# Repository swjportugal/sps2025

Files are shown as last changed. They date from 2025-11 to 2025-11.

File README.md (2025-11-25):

# SPS 2025 Nuremberg

SWJ will be showcasing its development capabilities in embedded Software and Hardware development, Validation & Testing and PMTs. Visit us in Hall 6, Stand 430.

This repository contains contact information and technical information for all demos showcased at SPS.

# SWJ at SPS: Daniel Mraß

<table border=0 >
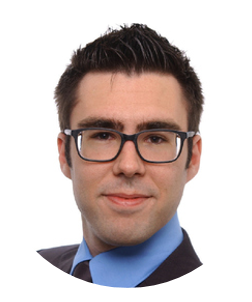
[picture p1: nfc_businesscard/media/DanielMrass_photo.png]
<tr><td></td>
<td>Angestellt, Projektingenieur<br/>
&nbsp; <br/>
SWJ Germany GmbH<br/>
Email: <a href="mailto:Daniel.Mrass@swj.de">Daniel.Mrass@swj.de</a><br/>
Web: <a href="www.swj.de">https://www.swj.de</a>
 </td></tr></table>

## NFC Business card

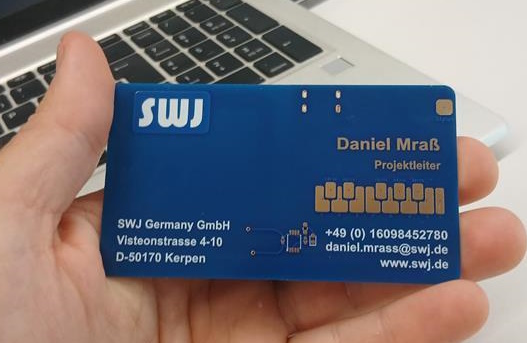
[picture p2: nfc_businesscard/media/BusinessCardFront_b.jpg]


The business card showcases an 0.8mm PCB in the traditional 85x55mm format.

We designed the PCB tracks in a **shape that creates an NFC antenna** and added an IC from NXP to provide quick transfer of contact information. A LED was also added,  so the user would get the unusual feedback of failed and successful attempts at NFC communication (short led pulse = failed; long led = succeeded)

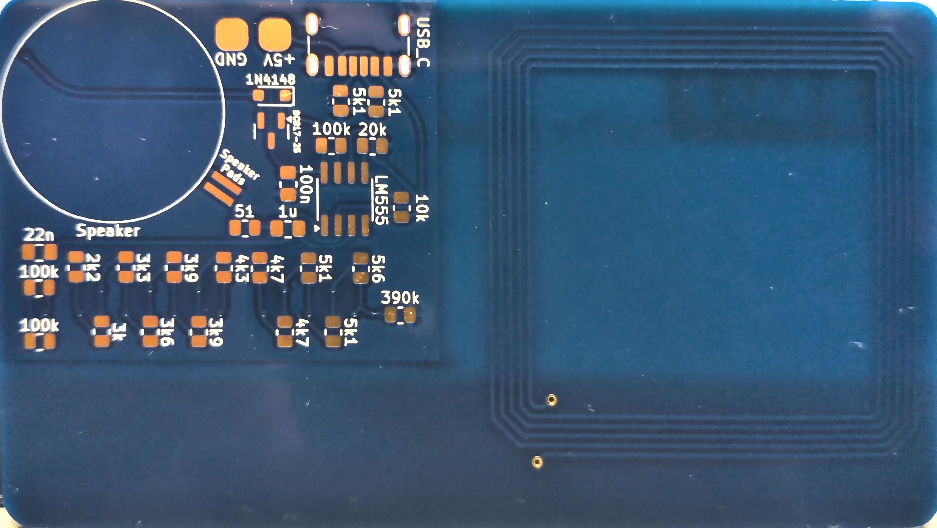
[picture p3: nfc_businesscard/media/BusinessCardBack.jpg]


Further, the team decided to add a "cool" factor to the business card by creating a **sound synthesizer** from the classic **555 timer**. What better way to flex your E/E knowledge? 

You can find the [BOM and schematics to populate this circuit and build your own synthesizer here](nfc_businesscard/ee_schematic/SWJ_NFC_BusinessCard.pdf).

## Smart controlled Windmills

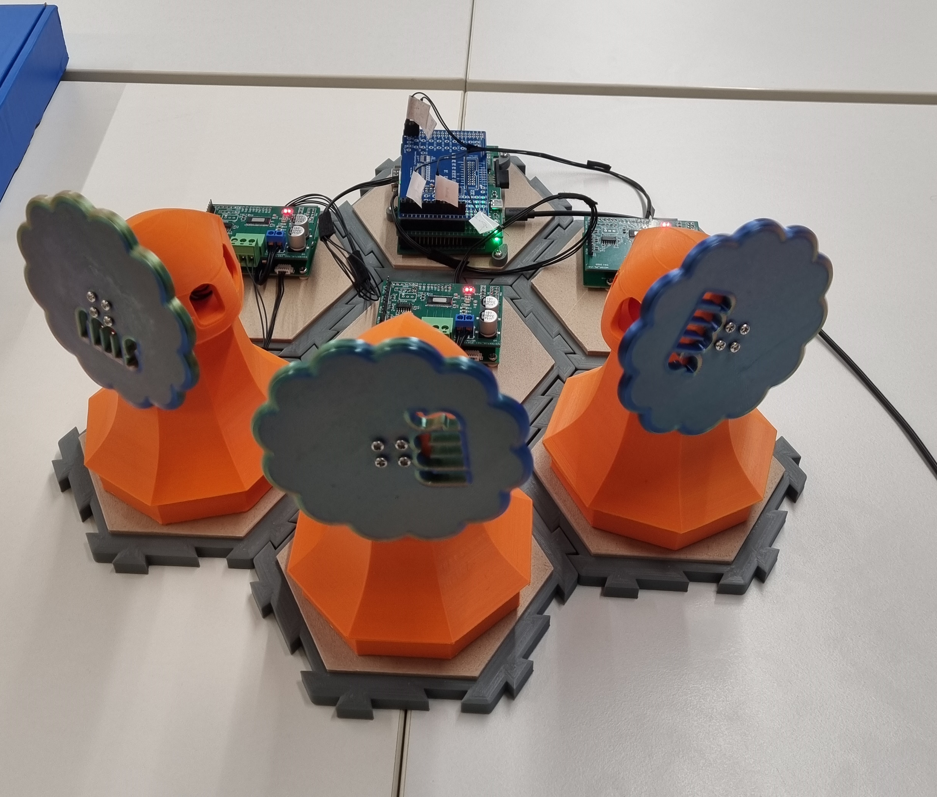
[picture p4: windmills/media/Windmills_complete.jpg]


The windmill demo showcases a distributed control system with a cascaded closed loop approach.

The solution is entirely designed by SWJ: mechanics, electronics and software.

A [detailed presentation can be found here](windmills/251110_WindmillDemo_Overview(Coisa).pdf) (incl. system diagrams and component identifications)

### System Architecture

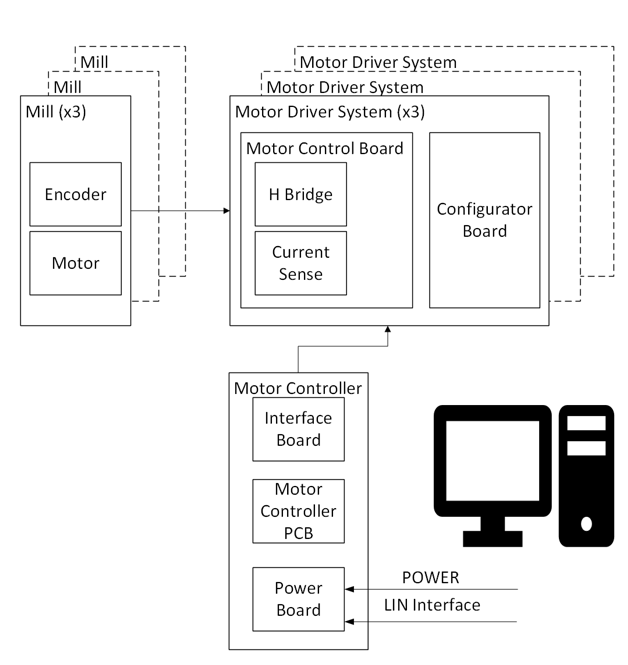
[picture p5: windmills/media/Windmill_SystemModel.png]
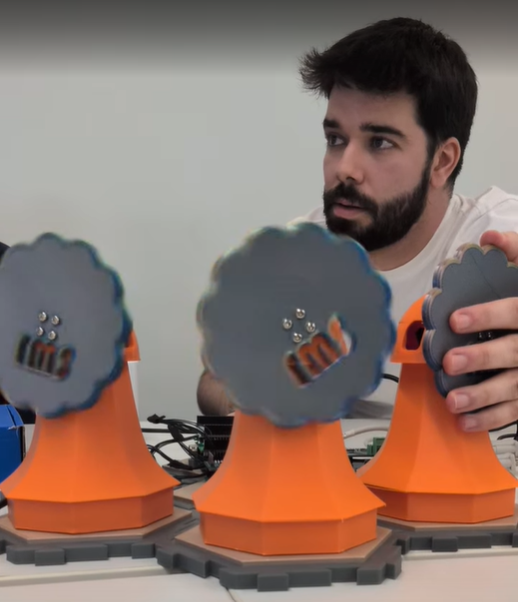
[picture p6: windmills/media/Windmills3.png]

   
At the **lower** level the windmills have a motor with an encoder on the output shaft (before the reduction box) to allow precise control of speed and continuously sense the real rotation and stall and error conditions.

At the **high level**, a control loop was created in Vector CANoe that continuously queries the motors status (current, speed, errors) and updates the target speed.
This creates dynamic behaviours that produce different, selectable, modes:

* Constant sum of speed: if any windmill is blocked or has its speed reduced, the other windmills spun up so that the sum of all speeds remains constant within the system
* Follow the leader: by manipulating one windmill, the others will follow (i.e. if you slow it down, the others slow down; if you block it, the others block too)
* Winding clock: if you spin up the windmill manually, the others spin up as well, and their speed slowly decays as if winding down a spring

#### This project is a combination of multiple disciplines:
* Electronics design: for the Windmill motor drivers and the master STM low level controller (speed)

Check the Schematics here: [ee_schematics](windmills/ee_schematics)

* Software (Embedded and Control): embedded software for the STM low level controller (speed), and CANoe high level control

Check the Software here: [sw_canoe_simulation](windmills/sw_canoe_simulation)

* Mechanical design: 3D models for the windmills, base and overall mounting points  

Find 3D models here: [3dmodels_mechanical](windmills/3dmodels_mechanical)

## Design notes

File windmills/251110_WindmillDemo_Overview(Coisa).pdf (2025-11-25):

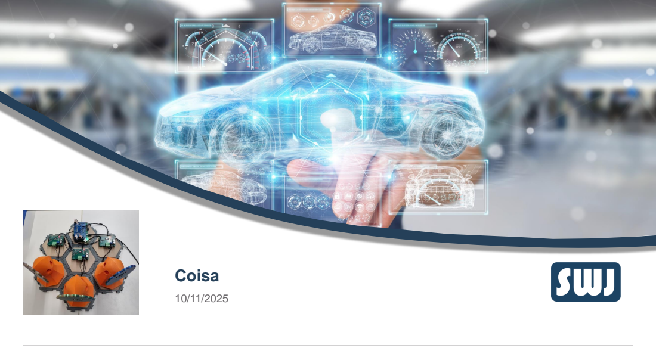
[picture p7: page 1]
Coisa

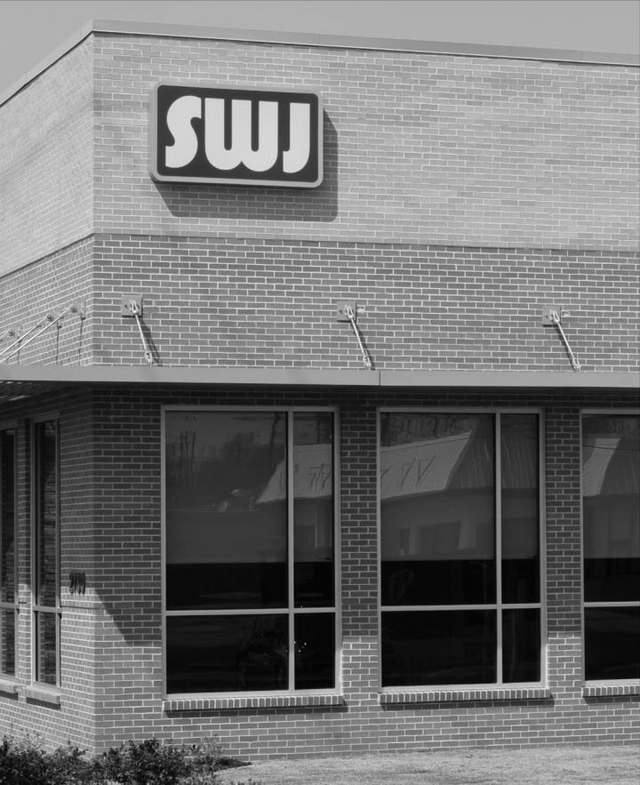
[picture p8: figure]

1

2

3

# Agenda

Copyright © 2022 SWJ. Alle Rechte vorbehalten. Vertraulich. | 2 | 25. November 2025

# Goals and Timeline

# PC control software

# Physical system

# Lessons learned

# Goals

- Coisa shall present some type of physical movement;
- A user shall be able to interact with Coisa;
- Coisa shall atract the atention;
- Coisa shall present SWJ capabilities.
3 | 25/11/2025

# Timeline

4 | 25/11/2025

# 20 Oct Hardware

# 10 Nov Software

# 25 Nov Fair Display

# Overall system

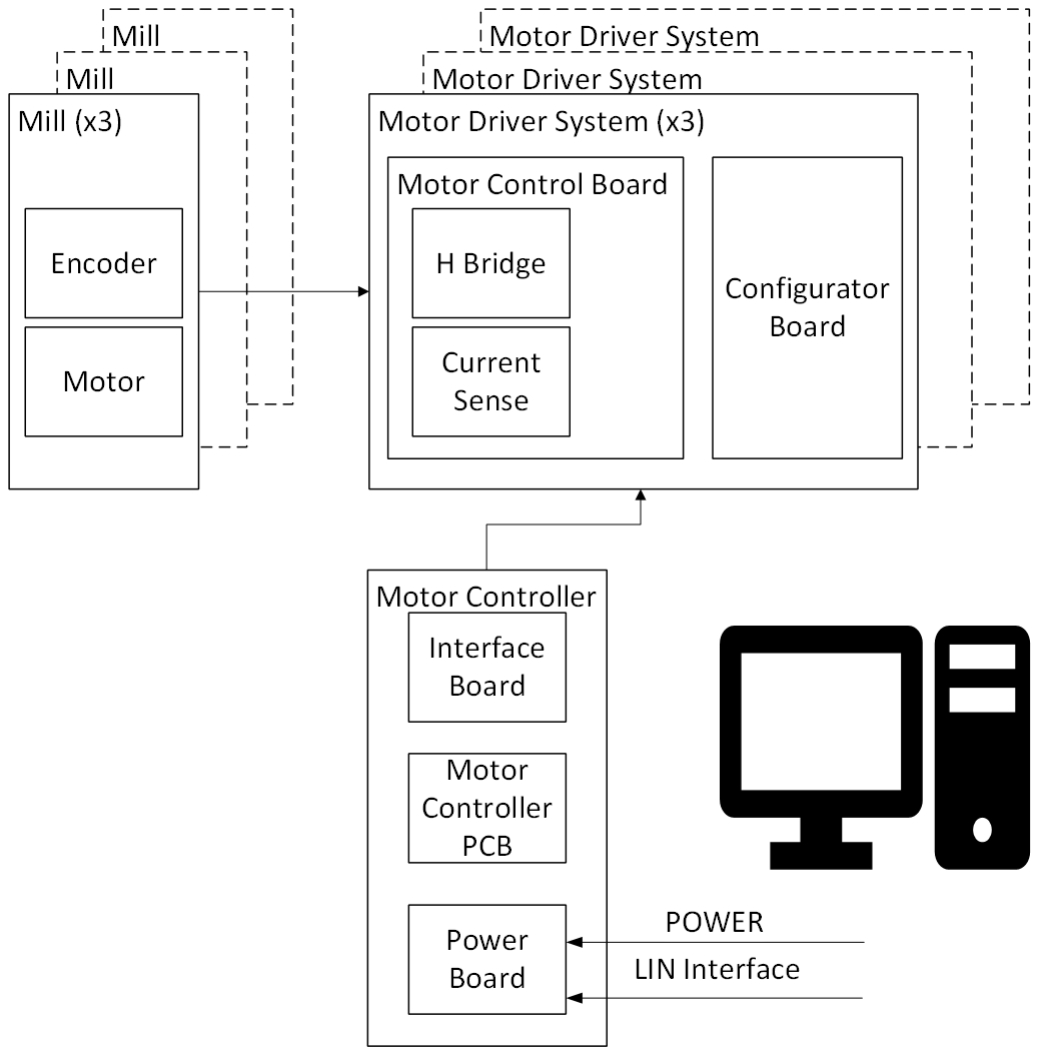
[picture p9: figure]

Copyright © 2022 SWJ. Alle Rechte vorbehalten. Vertraulich. | 5 | 25. November 2025

# - The visitor is invited to touch the mills to test the

system response;

- PC controls the high level behavior, mills interaction;

# - The motor controller controls each mill individualy to a

setpoint of speed.

# PC Software

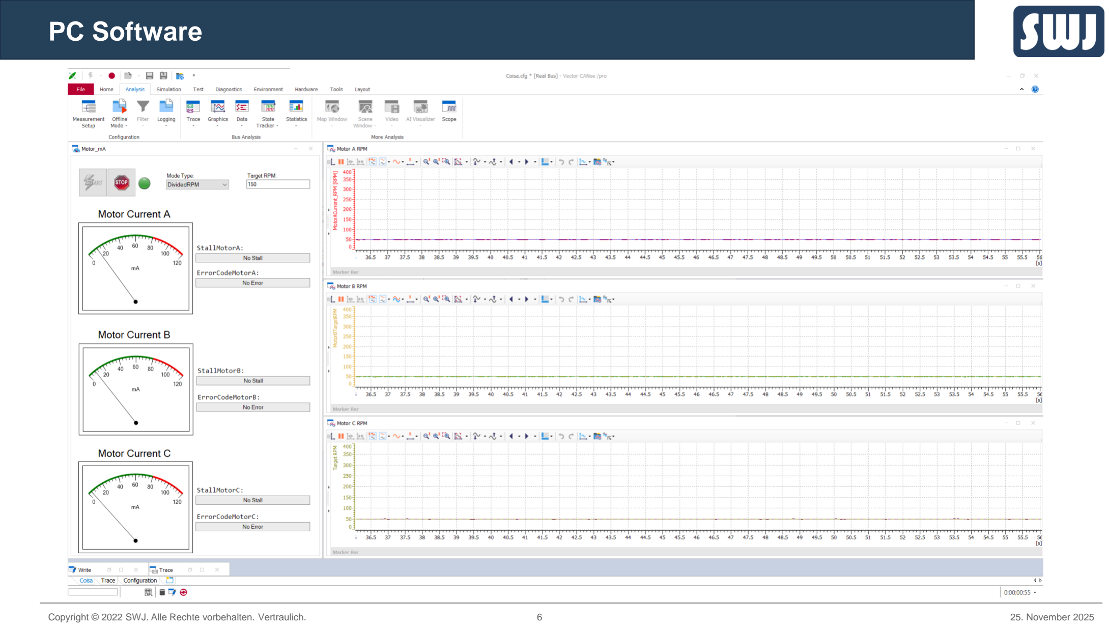
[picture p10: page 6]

Copyright © 2022 SWJ. Alle Rechte vorbehalten. Vertraulich. | 6 | 25. November 2025

# Physical System

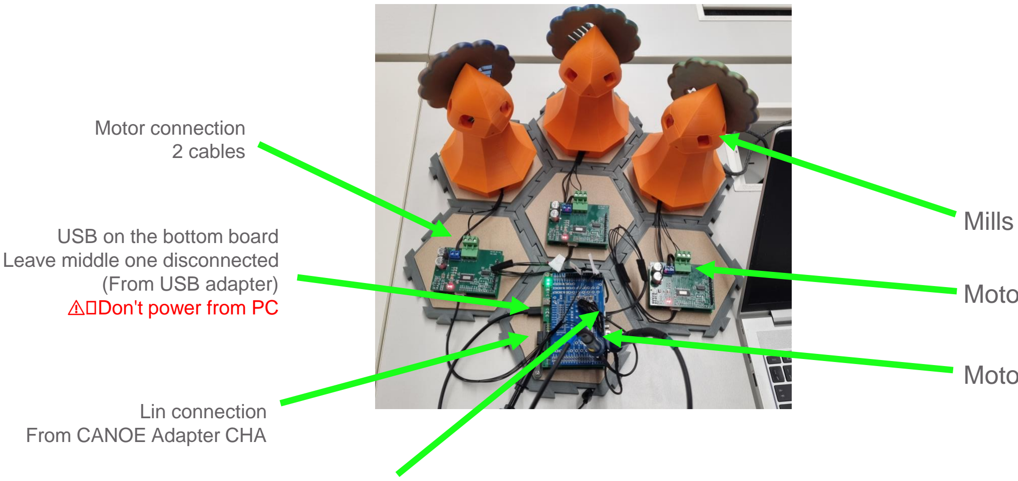
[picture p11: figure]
Mills USB on the bottom board; Leave middle one disconnected (From USB adapter) ⚠️Don't power from PC; Lin connection From CANOE Adapter CHA; Motor connection 2 cables

Copyright © 2022 SWJ. Alle Rechte vorbehalten. Vertraulich. | 7 | 25. November 2025

# Motor Driver

# Motor Controller

# Motors A to C labeled

# Embedded Software Architecture

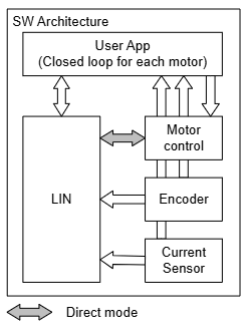
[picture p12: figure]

Copyright © 2022 SWJ. Alle Rechte vorbehalten. Vertraulich. | 8 | 25. November 2025

# Timming and controller

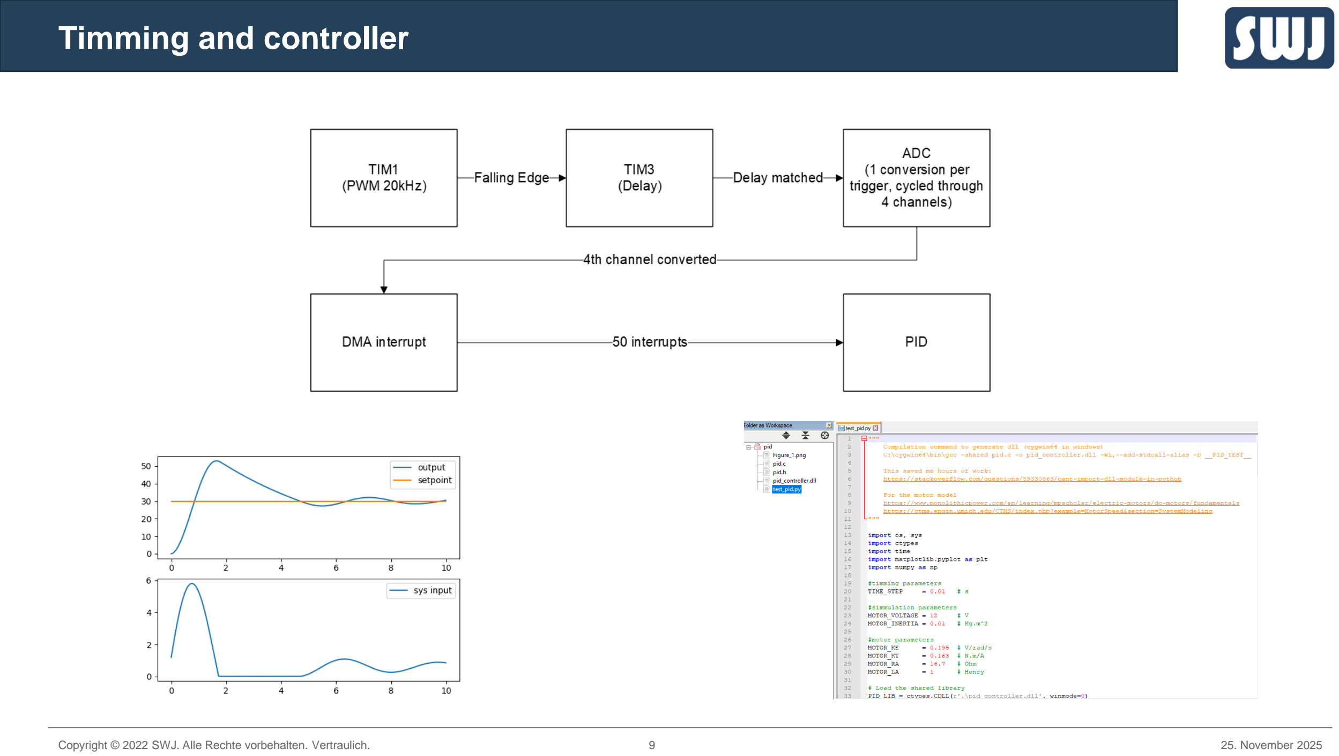
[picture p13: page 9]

Copyright © 2022 SWJ. Alle Rechte vorbehalten. Vertraulich. | 9 | 25. November 2025

# State machine

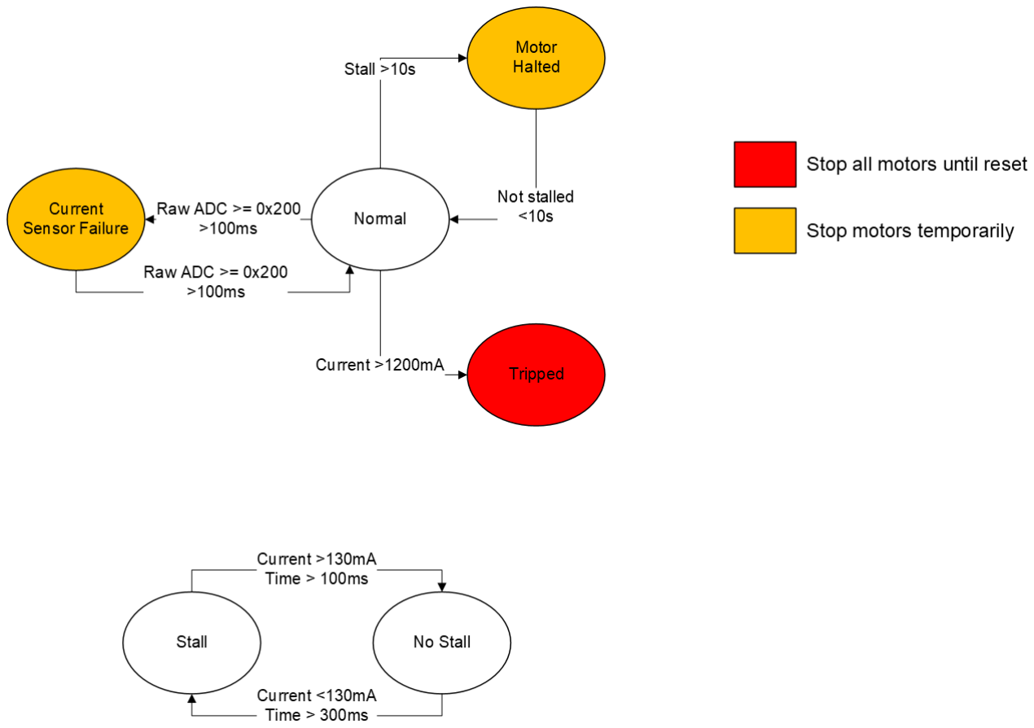
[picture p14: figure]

Copyright © 2022 SWJ. Alle Rechte vorbehalten. Vertraulich. | 10 | 25. November 2025

# Lessons Learned

Copyright © 2022 SWJ. Alle Rechte vorbehalten. Vertraulich. | 11 | 25. November 2025

# - Hardware

- Usage of protection mechanisms.

# DANKE

## taiku

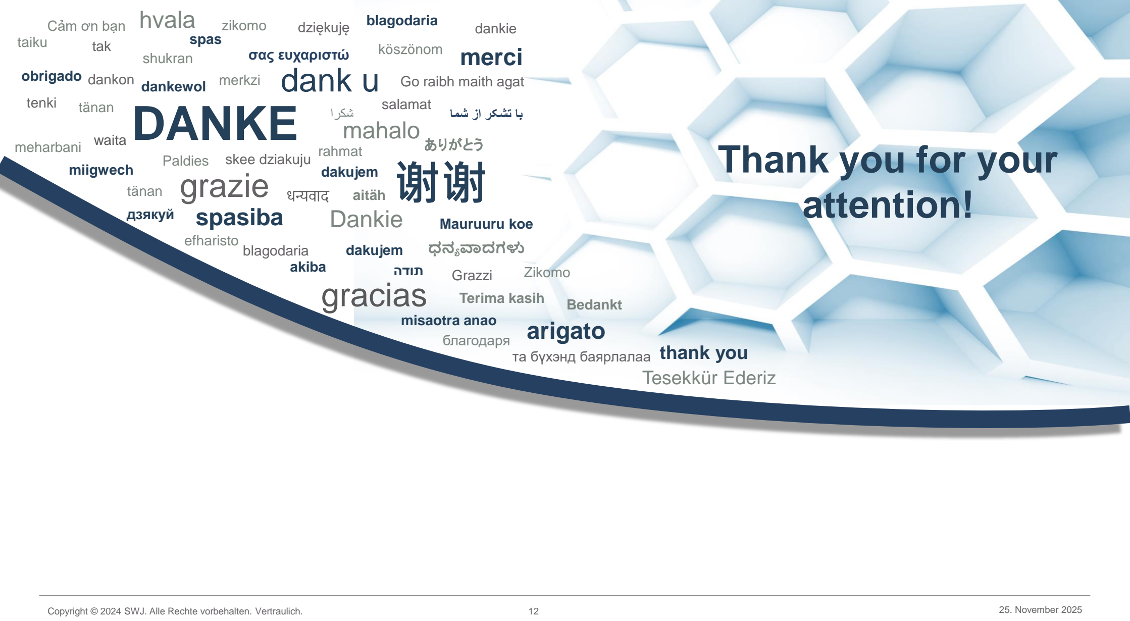
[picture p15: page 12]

# thank you

## tänan

## meharbani

# hvala

# Dankie

## ありがとう

## شكرا

## благодаря

## tak

# grazie

## dankon

## aitäh

## salamat

# gracias

# arigato

## dakujem

## shukran obrigado

miigwech | dakujem

## tenki

## waita

## spas

## merkzi

## efharisto blagodaria

## dankie

# spasiba

## Paldies

# Tesekkür Ederiz

## Bedankt

tänan | 谢谢

## σας ευχαριστώ

## תודה

# mahalo

## धन्यवाद

## Terima kasih

## Go raibh maith agat

## ಧನ್ಯ ವಾದಗಳು

## misaotra anao

## Grazzi

## Mauruuru koe

# dank u

## та бүхэнд баярлалаа

## Zikomo

## با تشکر از شما

Cảm ơn bạn | dziękuję

## дзякуй

## rahmat

## köszönom

## blagodaria

## skee dziakuju

## akiba

## zikomo

## dankewol

# merci

# Thank you for your attention!

Copyright © 2024 SWJ. Alle Rechte vorbehalten. Vertraulich. | 12 | 25. November 2025

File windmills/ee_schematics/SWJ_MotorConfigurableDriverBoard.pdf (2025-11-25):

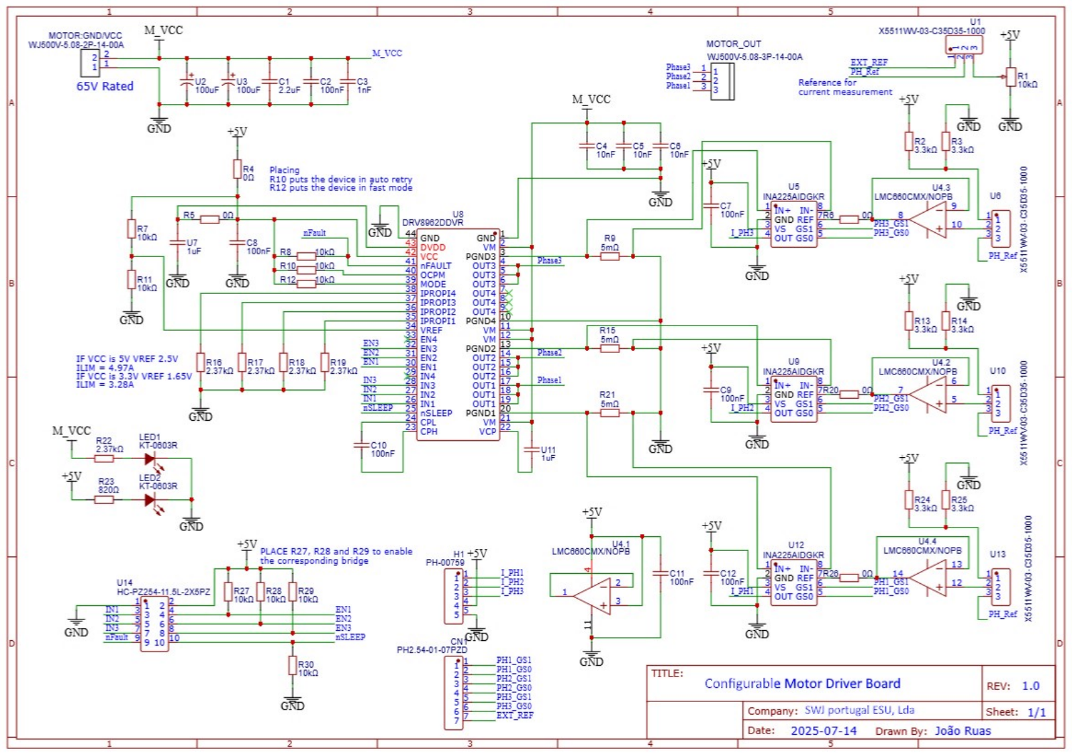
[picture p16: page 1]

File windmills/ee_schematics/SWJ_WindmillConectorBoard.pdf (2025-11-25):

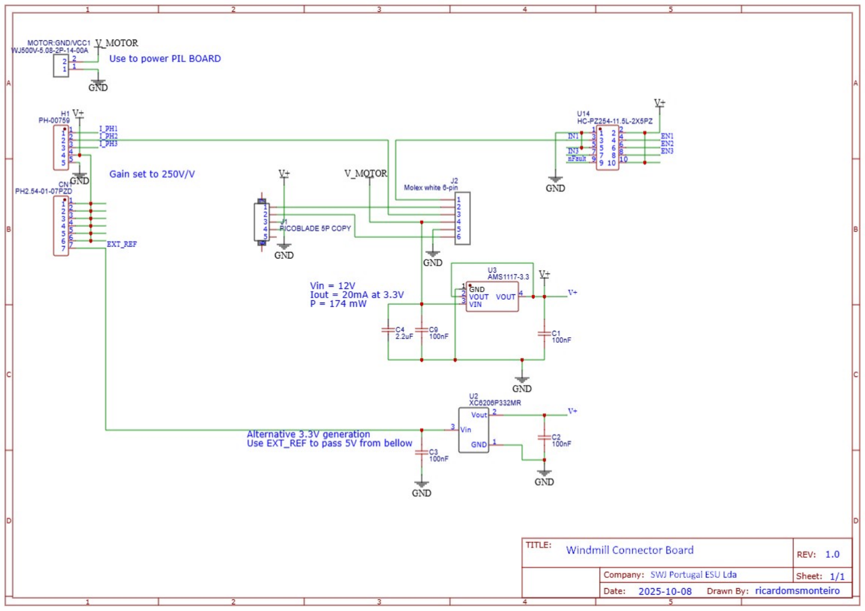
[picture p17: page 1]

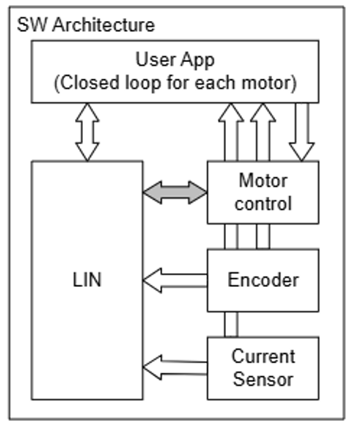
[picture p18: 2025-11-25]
windmills/media/SystemArch.png

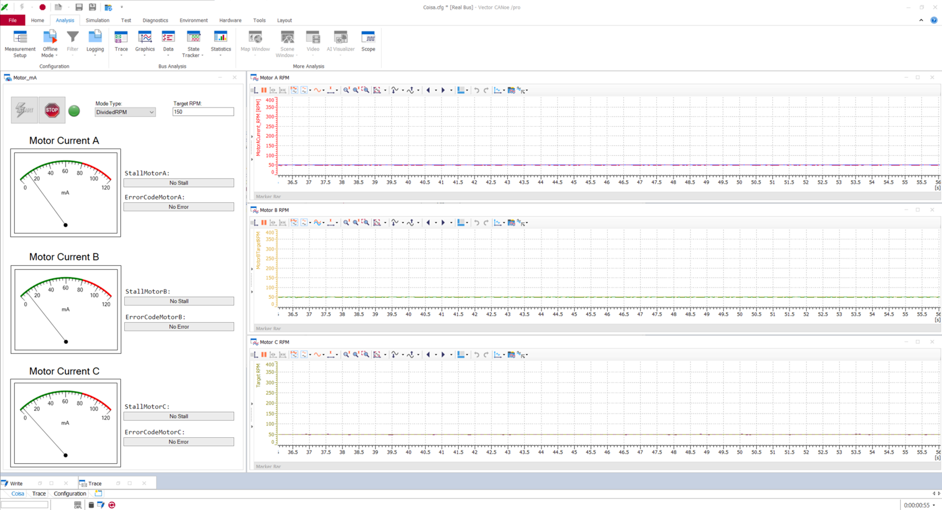
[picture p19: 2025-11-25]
windmills/media/WindMills CANoe.png

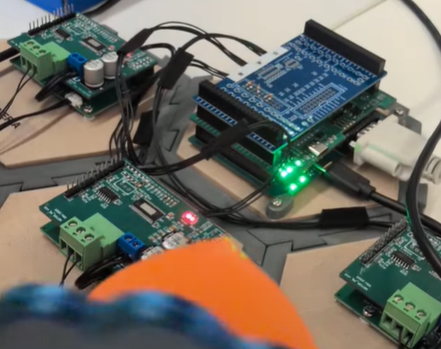
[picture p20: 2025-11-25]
windmills/media/Windmills5.png

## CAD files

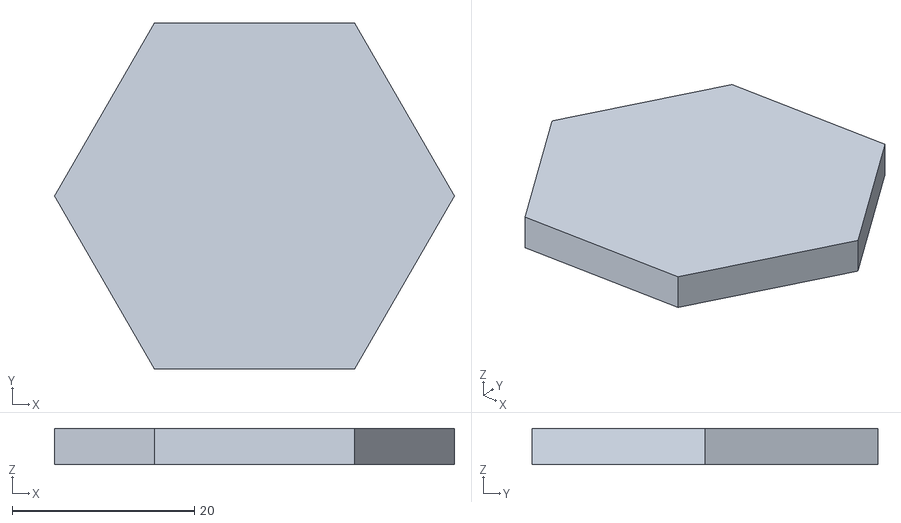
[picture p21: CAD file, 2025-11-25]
windmills/3dmodels_mechanical/base/HeroscapeTile_Reimagined_-_Top_blank.stl
43.9 x 38.0 x 4.00

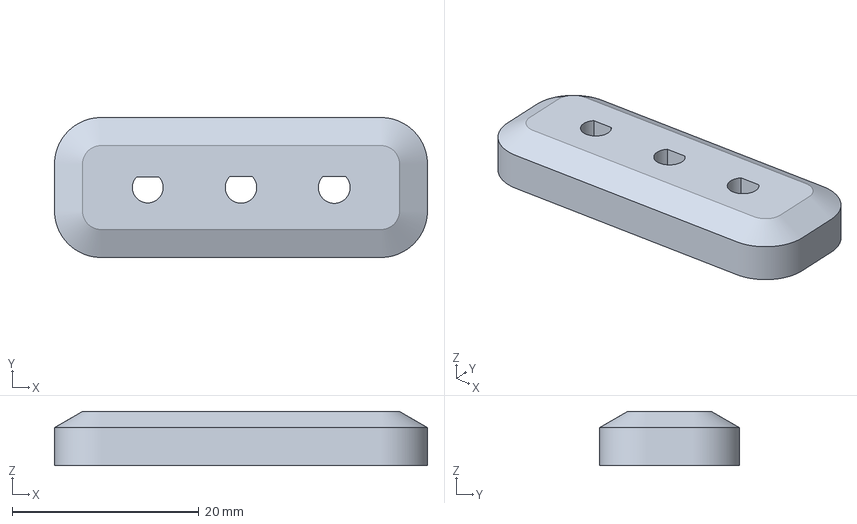
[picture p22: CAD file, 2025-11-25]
windmills/3dmodels_mechanical/calib/calib_shaft_1.3mf
40.0 x 15.0 x 5.80 mm

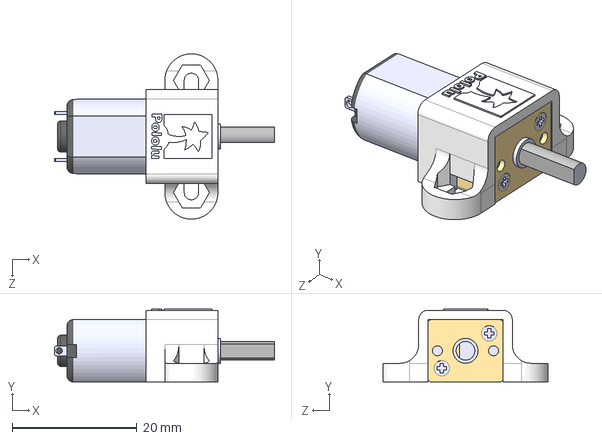
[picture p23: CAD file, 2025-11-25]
windmills/3dmodels_mechanical/Tower/supporting_shapes/micro-metal-gearmotor-with-1086-bracket.step
35.3 x 11.7 x 26.5 mm

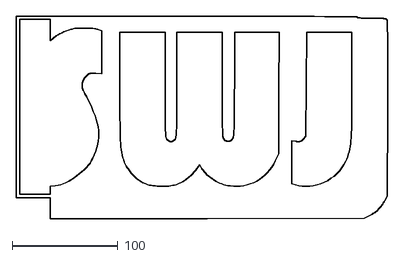
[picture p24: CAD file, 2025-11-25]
windmills/3dmodels_mechanical/Wheel/logo/SWJ-logo.dxf
351.9 x 192.0

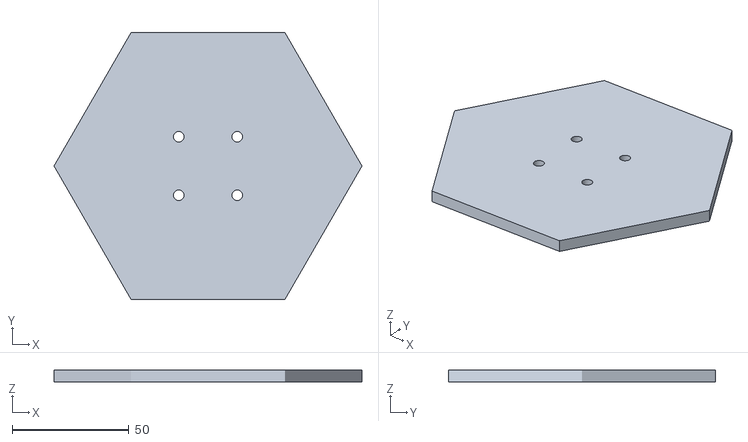
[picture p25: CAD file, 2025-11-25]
windmills/3dmodels_mechanical/base/Tile-Top-moinho.stl
131.7 x 114.1 x 5.00

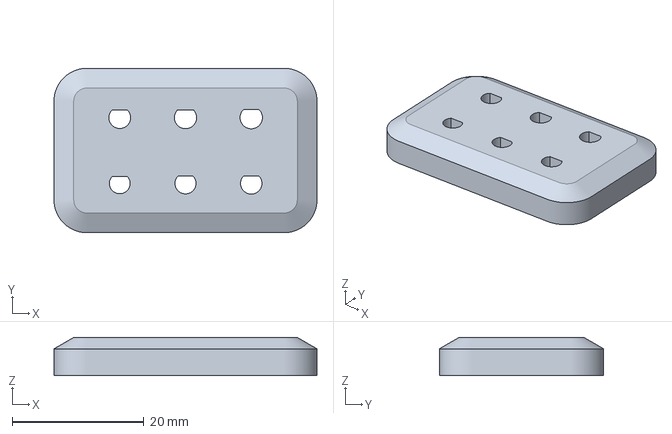
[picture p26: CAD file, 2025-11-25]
windmills/3dmodels_mechanical/calib/calib_shaft_2.3mf
40.0 x 25.0 x 5.80 mm

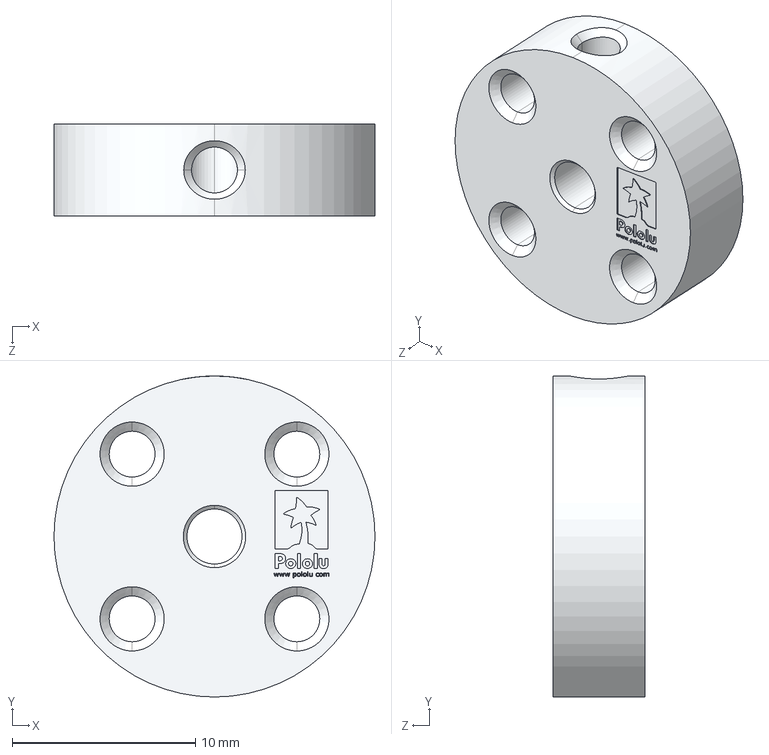
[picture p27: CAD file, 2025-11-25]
windmills/3dmodels_mechanical/Tower/supporting_shapes/pololu-universal-aluminum-mounting-hub-for-3mm-shaft-m3-holes.step
17.5 x 17.5 x 5.00 mm

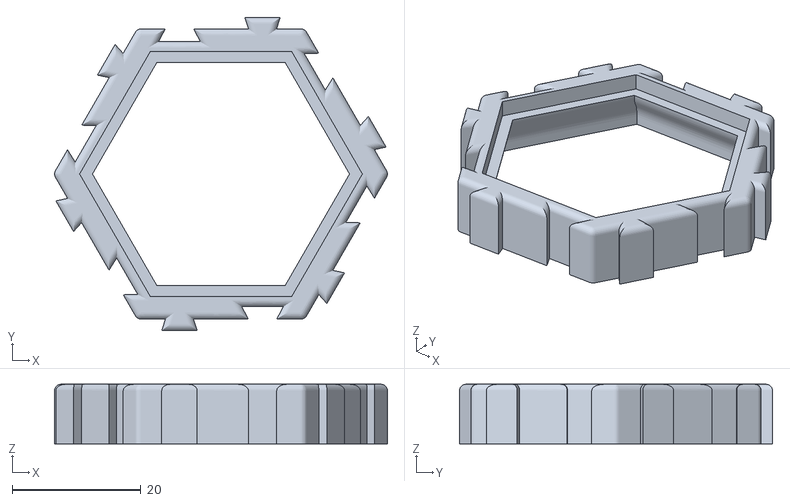
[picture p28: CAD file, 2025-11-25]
windmills/3dmodels_mechanical/base/HeroscapeTile_Reimagined_-_Base.stl
51.7 x 48.6 x 9.25

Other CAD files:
windmills/3dmodels_mechanical/base/Tile-Top-pcb.stl
windmills/3dmodels_mechanical/calib/calib_shaft_1.stl
windmills/3dmodels_mechanical/calib/calib_shaft_2.stl

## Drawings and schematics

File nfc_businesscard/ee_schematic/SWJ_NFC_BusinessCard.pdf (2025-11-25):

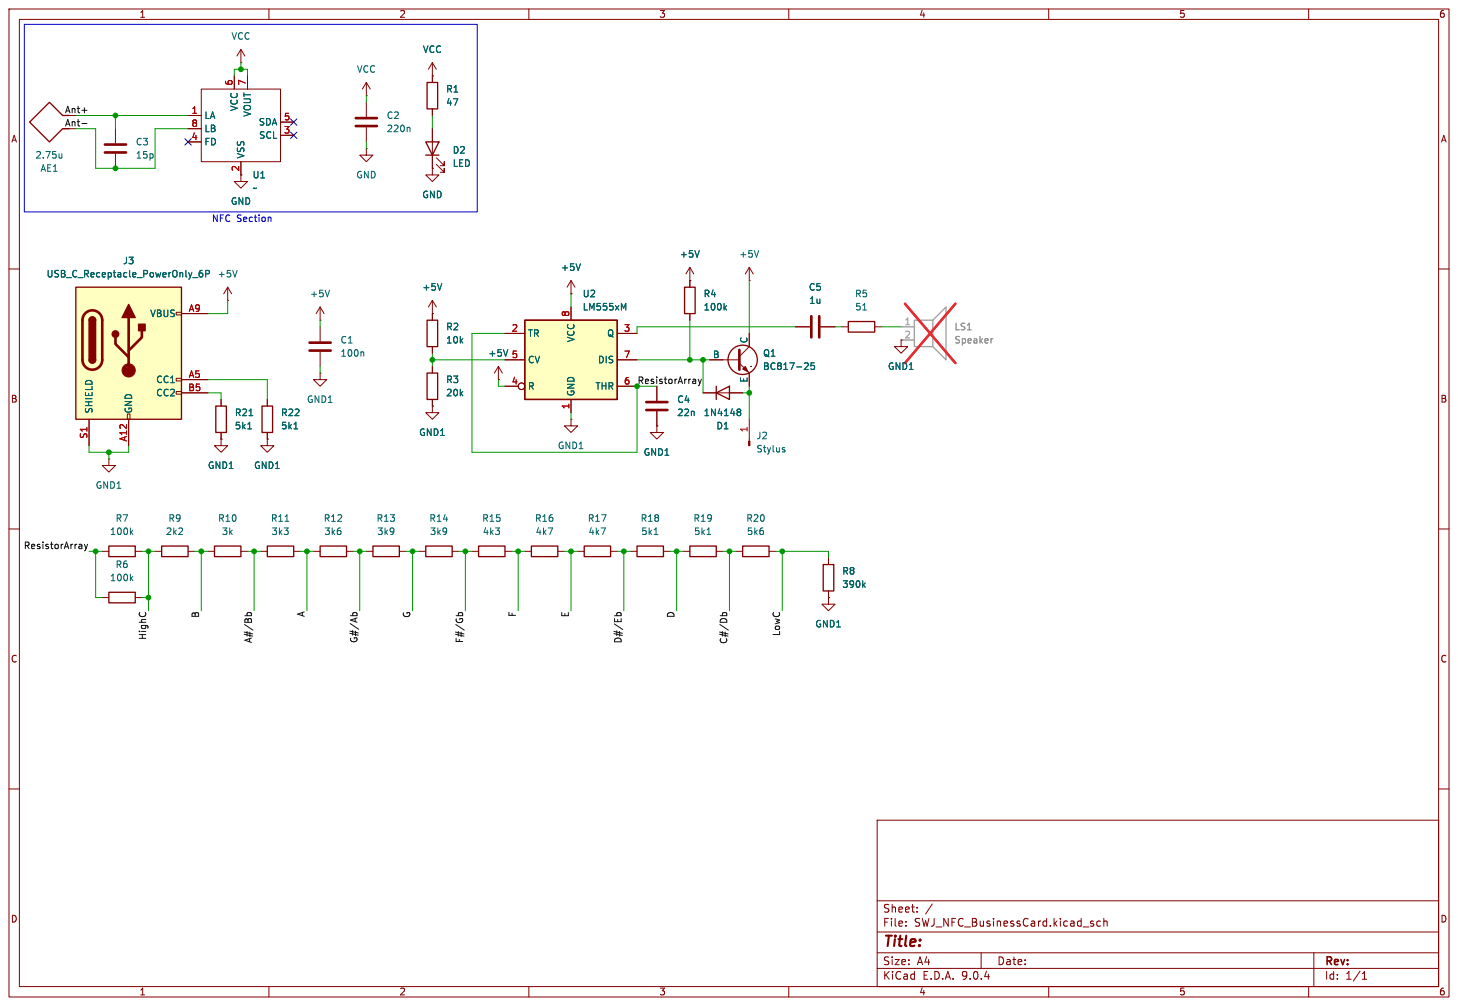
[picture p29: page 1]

Id: 1/1 Title: File: SWJ_NFC_BusinessCard.kicad_sch Sheet: /
